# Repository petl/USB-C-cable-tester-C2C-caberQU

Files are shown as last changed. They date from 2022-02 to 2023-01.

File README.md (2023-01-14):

# USB C cable tester - C2C caberQU
Can my cable support USB 2.0/3.0/3.1/3.2, power delivery? Is a wire broken?

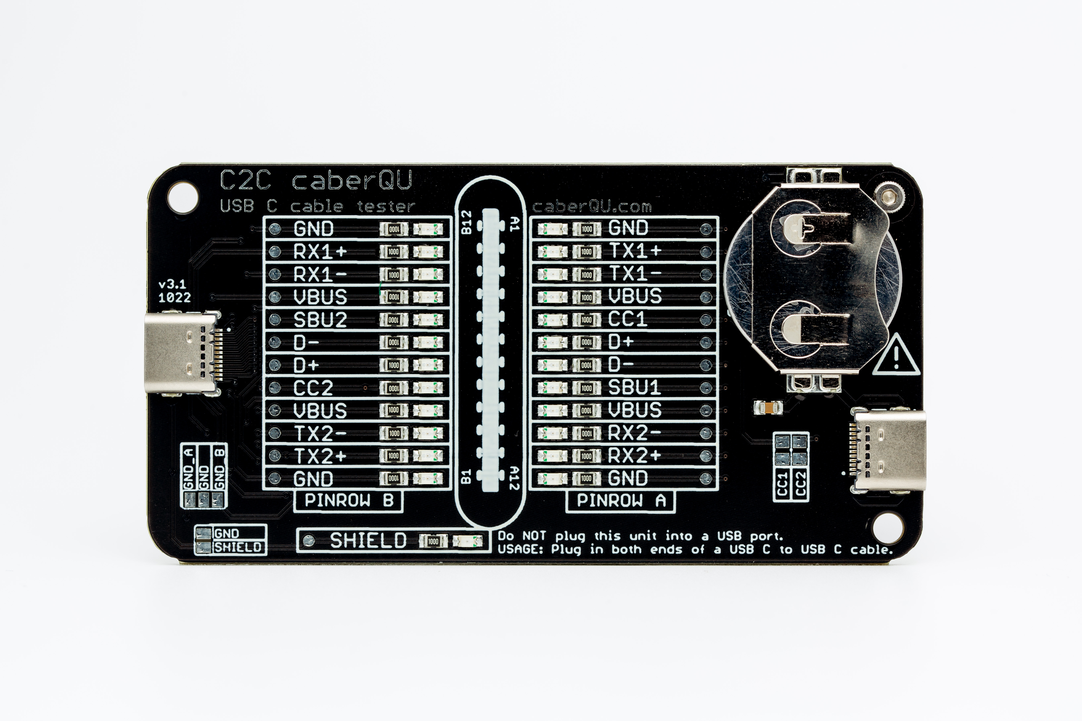
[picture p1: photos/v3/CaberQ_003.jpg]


Website: https://caberqu.com

#### What is it?

The C2C caberQU board applies a voltage to all pins of a cable and measures which ones are connected to the other end. It features LEDs for each of the 24 pins and even shield. So in total 25 LEDs offer all possible combinations for USB-C receptacle pin usage in different modes:

- USB 2.0/1.1
- USB Power Delivery
- USB 3.0/3.1/3.2
- Alternate Mode
- Debug Accessory Mode
- Audio Adapter Accessory Mode

See [the manual](https://github.com/petl/USB-C-cable-tester-C2C-caberQU/blob/main/documentation/v3/caberQU_manual_v3.2_compressed.pdf) to check which pin should be connected to where and get more infos about the USB-C connector. 

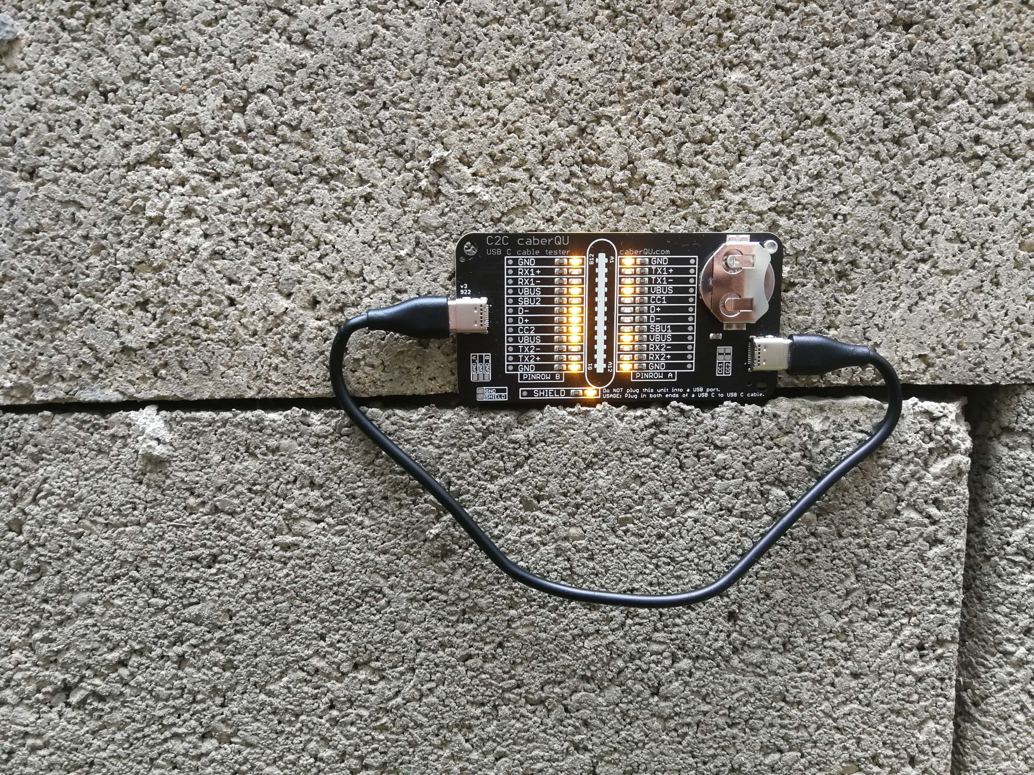
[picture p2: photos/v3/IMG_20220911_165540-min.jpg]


#### Why did you make it?

The amount of possible USB C cable combinations is endless. If you use the wrong cable, data transmission may be slower than possible or certain devices may not work at all. In the USB C standard, the cable plays an important role and has to advertise itself as such. All of them need to have certain pins connected, some need to be grounded, some need to have resistors attached. 

#### What makes it special?

Unfortunately there is no easy way to extract whether a certain cable can support a certain use case. If a cable has a broken pin, that makes it even worse, due to their unpredictable behavior. The C2C caberQU cable tester solves this once and for all. By flipping the USB connectors, the opposing LEDs for some pins light up due to them not being mirrored. That's on purpose and defined in the USB C standard. The product is sold with one CR2032, the PCB and some basic instructions. The USB C cable is not included. You have to extract the needed pins for your desired usage on your own, unfortunately that can not be done universally for all possible combinations.

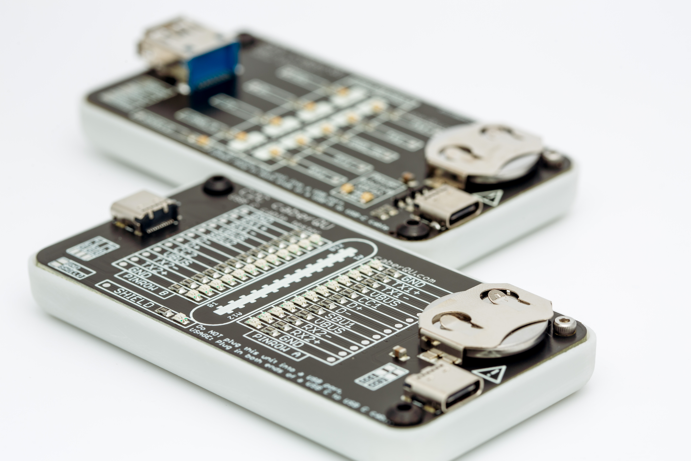
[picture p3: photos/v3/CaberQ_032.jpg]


No dedicated power supply is needed, all necessary power is supplied via the CR2032 battery.

Please note that if you have a cheaper shipping option I'm gladly using it and refunding you the difference. The item still is a prototype. It is working as intended, but funny quirks and other things are possible. It is not certified and only suited for prototyping. 

If you have any questions, just shoot me a message!

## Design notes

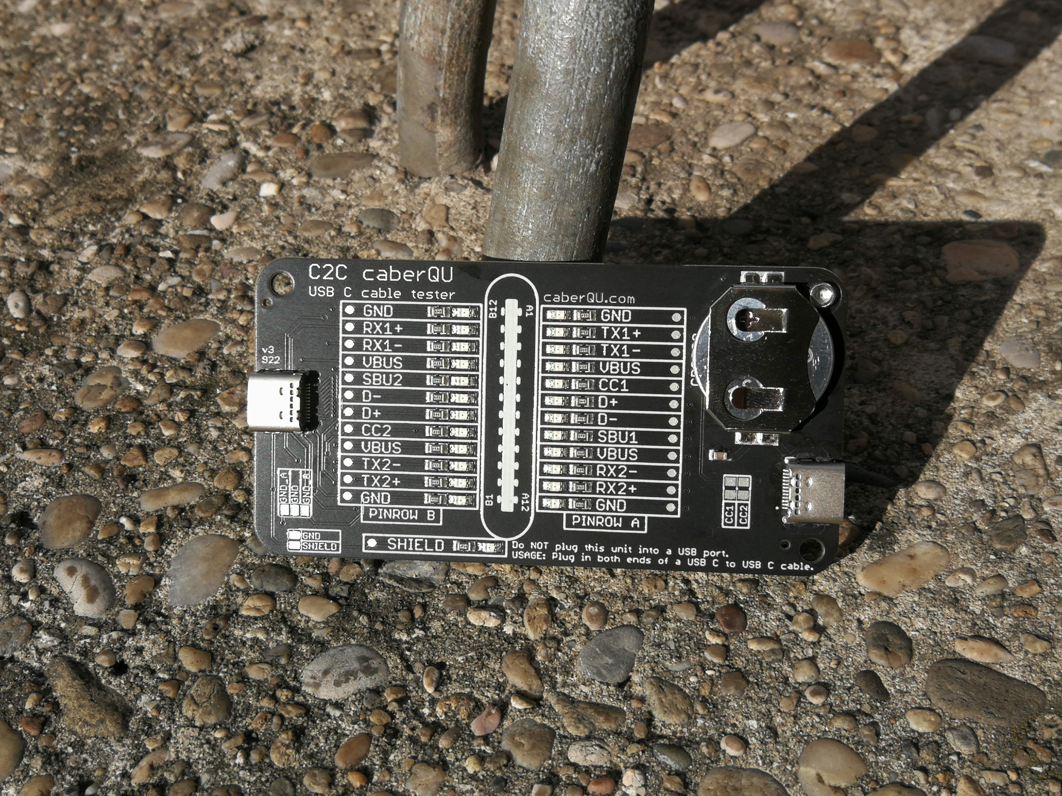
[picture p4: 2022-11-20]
photos/v3/IMG_20220911_164710-min.jpg

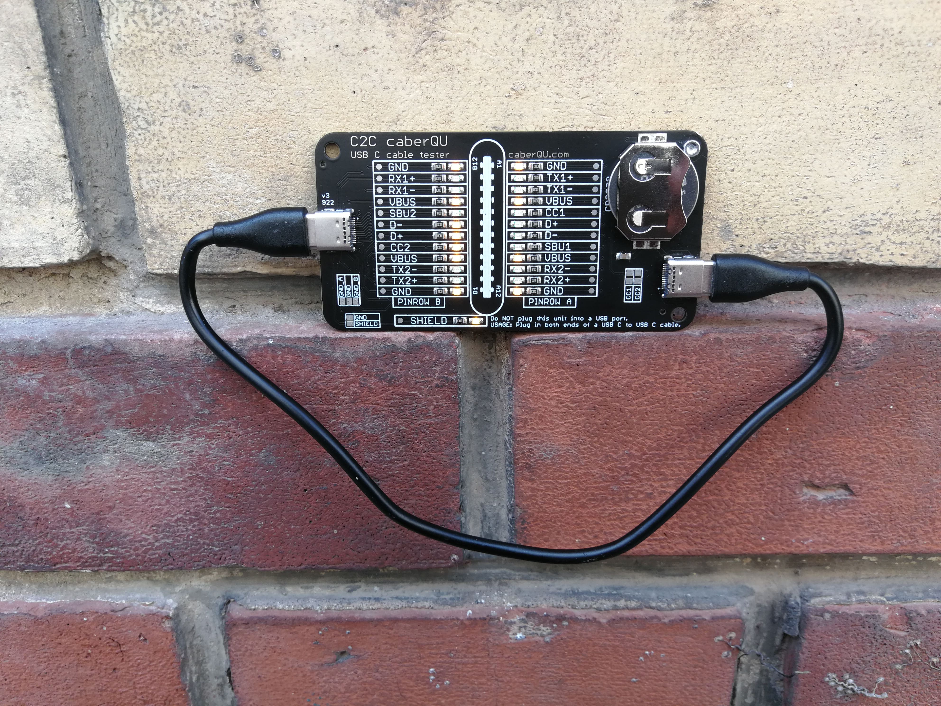
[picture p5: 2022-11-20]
photos/v3/IMG_20220911_165913-min.jpg

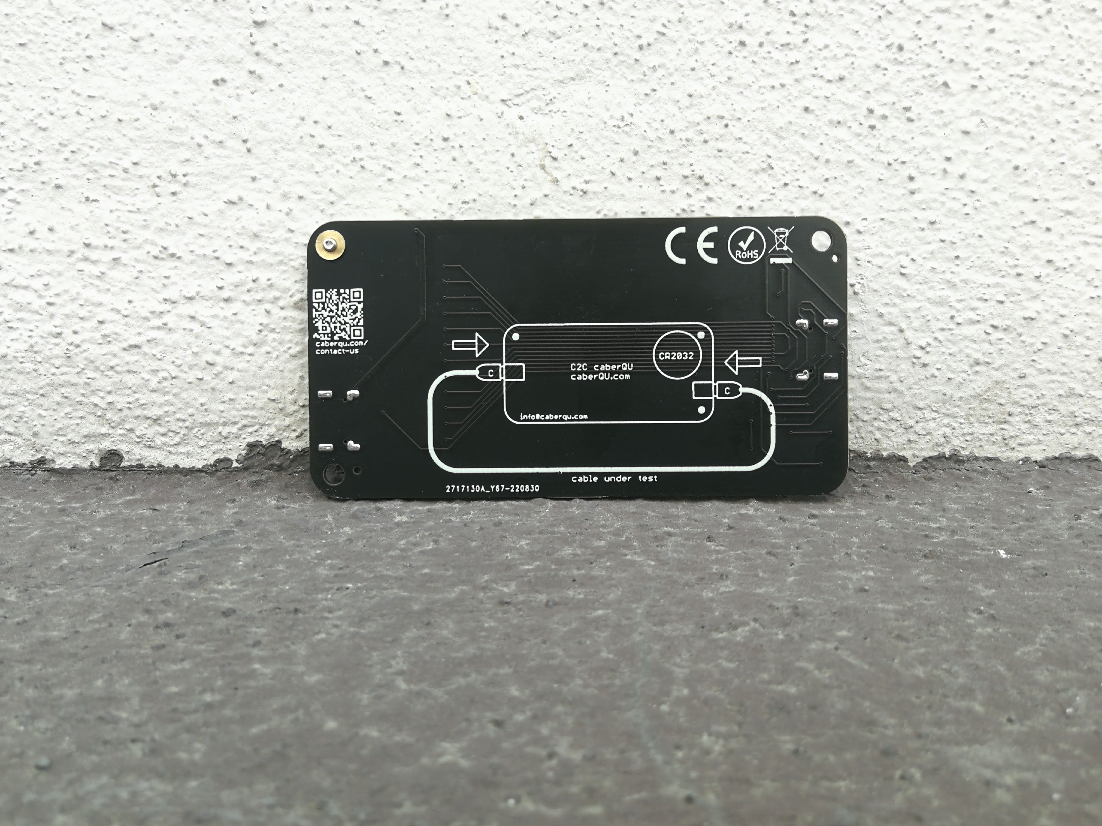
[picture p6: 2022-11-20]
photos/v3/IMG_20220911_163435-min.jpg

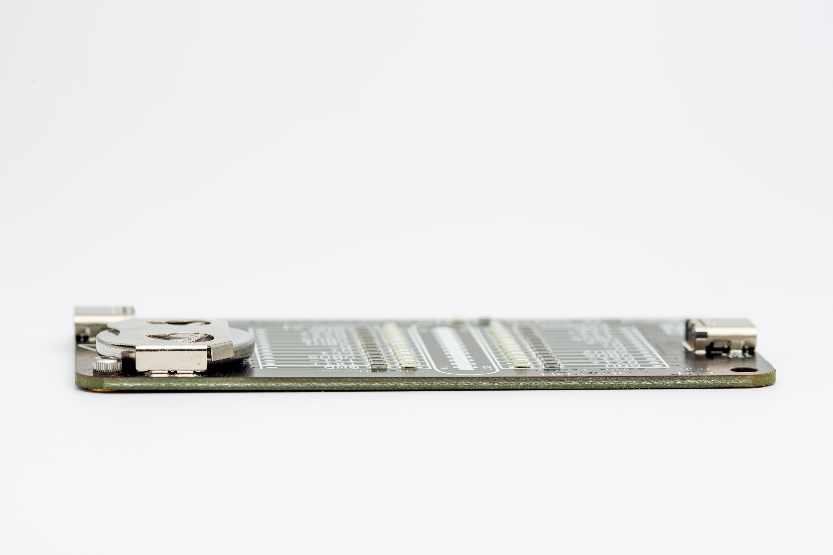
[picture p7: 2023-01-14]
photos/v3/CaberQ_010.jpg

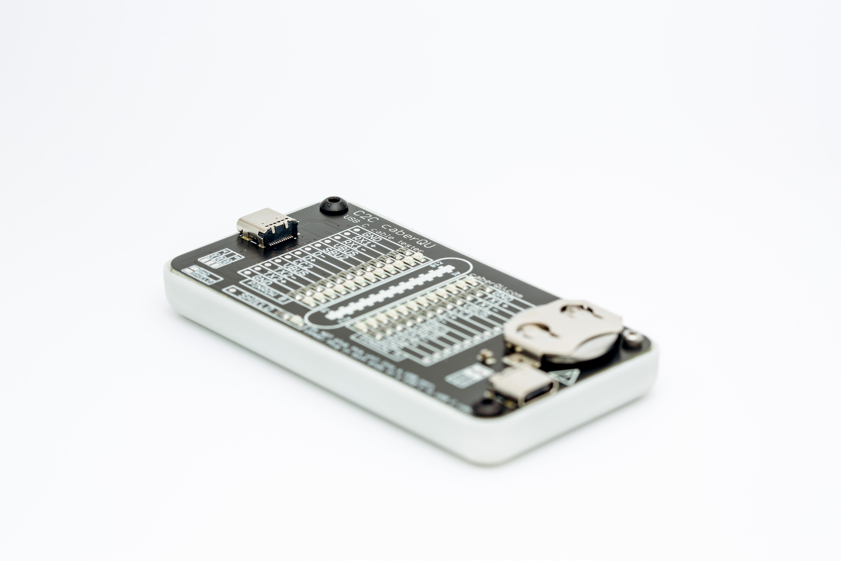
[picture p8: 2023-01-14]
photos/v3/CaberQ_027.jpg

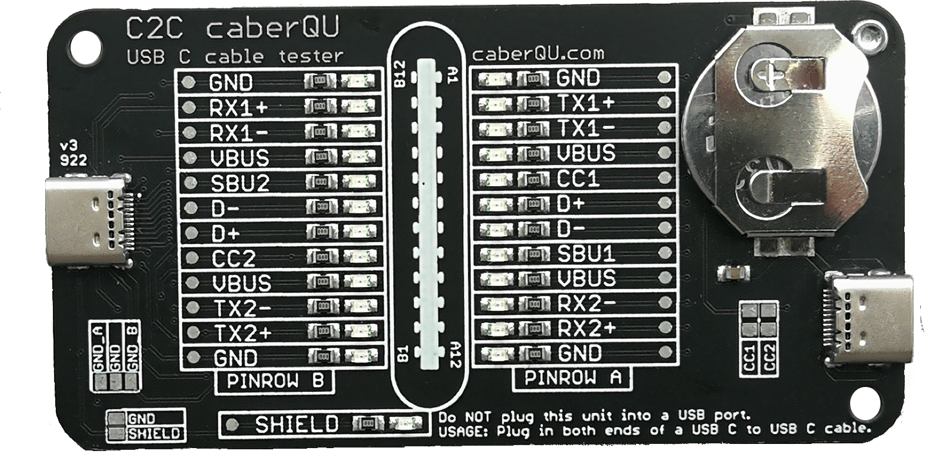
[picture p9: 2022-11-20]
photos/v3/C2C_front_transparent_bg.png

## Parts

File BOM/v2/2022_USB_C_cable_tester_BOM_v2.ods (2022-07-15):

Name | Value | Layout | Package
USB C cable tester
CR2032
PCB
CR2032 holder |  | G1 | CR2032-HOLDER-C964833
MLC Cap | 1u | C1 | C0805
LED yellow |  | LED1 LED2 LED3 LED4 LED5 LED6 LED7 LED8 LED9 LED10 LED11 LED12 LED13 LED14 LED15 LED16 LED17 LED18 LED19 LED20 LED21 LED22 LED23 LED24 LED25 | CHIPLED_0805
Resistor | 100 | R1 R2 R3 R4 R5 R6 R7 R8 R9 R10 R11 R12 R13 R14 R15 R16 R17 R18 R19 R20 R21 R22 R23 R24 R25 | R0805
USB C |  | J3 J4

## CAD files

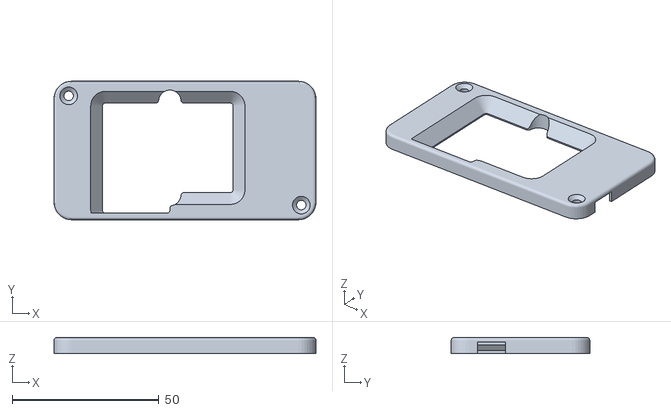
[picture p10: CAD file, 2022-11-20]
mechanics/stl/2022_USB_C_cable_tester_v3_full_enclosure_v4.STL
89.2 x 47.2 x 5.50

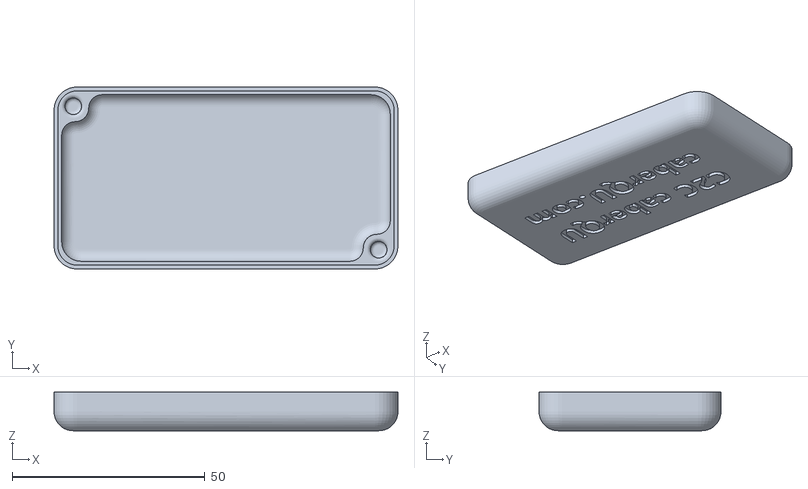
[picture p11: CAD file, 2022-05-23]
mechanics/stl/2022_USB_C_cable_tester_v2_Kickstarter_holder_M3_thinwall_v3.STL
89.2 x 47.2 x 10.0

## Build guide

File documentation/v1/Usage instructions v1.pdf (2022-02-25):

Usage instructions | 2.2022 p. 1/2

## Usage instructions

Congratulations on buying a great product for tinkering, debugging, testing and many other things. This manual will guide you through the usage instructions for the C2C caberQU USB C cable tester. Please read this carefully in order to be able to assemble everything without problems. If you face any problems, don‘t hesitate to write a mail.

Information:
Insert a CR2032 cell with the positive side („+“) facing up into the cell holder. Make sure not to short circuit it and don‘t use damaged or wrong batteries.
The C2C caberQU board applies a voltage to all pins of a cable and measures which ones are connected to the other end. It features LEDs for each of the 24 pins and even shield. So in total 25 LEDs offer all possible combinations for USB-C receptacle pin usage in different modes:
- USB 2.0/1.1
- USB Power Delivery
- USB 3.0/3.1/3.2
- Alternate Mode
- Debug Accessory Mode
- Audio Adapter Accessory Mode
See https://en.wikipedia.org/wiki/USB-C (https://en.wikipedia.org/wiki/USB-C#USB-C_receptacle_pin_usage_in_different_modes) to check which pin should be connected to where.
The amount of possible USB C cable combinations is endless. If you use the wrong cable, data transmission may be slower than possible or certain devices may not work at all. In the USB C standard, the cable plays an important role and has to advertise itself as such. All of them need to have certain pins connected, some need to be grounded, some need to have resistors attached. Unfortunately there is no easy way to extract whether a certain cable can support a certain use case. If a cable has a broken pin, that makes it even worse, due to their unpredictable behavior. The C2C caberQU cable tester solves this once and for all. By flipping the USB connectors, the opposing LEDs for some pins light up due to them not being mirrored. That's on purpose and defined in the USB C standard. The product is sold with one CR2032, the PCB and some basic instructions. You have to extract the needed pins for your desired usage on your own, unfortunately that can not be done universally for all possible combinations.
No dedicated power supply is needed, all necessary power is supplied via the CR2032 battery. Please note that if you have a cheaper shipping option I'm gladly using it and refunding you the difference. The item still is a prototype. It is working as intended, but funny quirks and other things are possible. It is not certified and only suited for prototyping.
If you have any questions, just shoot me a message!

Have fun tinkering and thanks for buying!

https://www.tindie.com/stores/petl/ | C2C caberQU - USB C cable tester v1

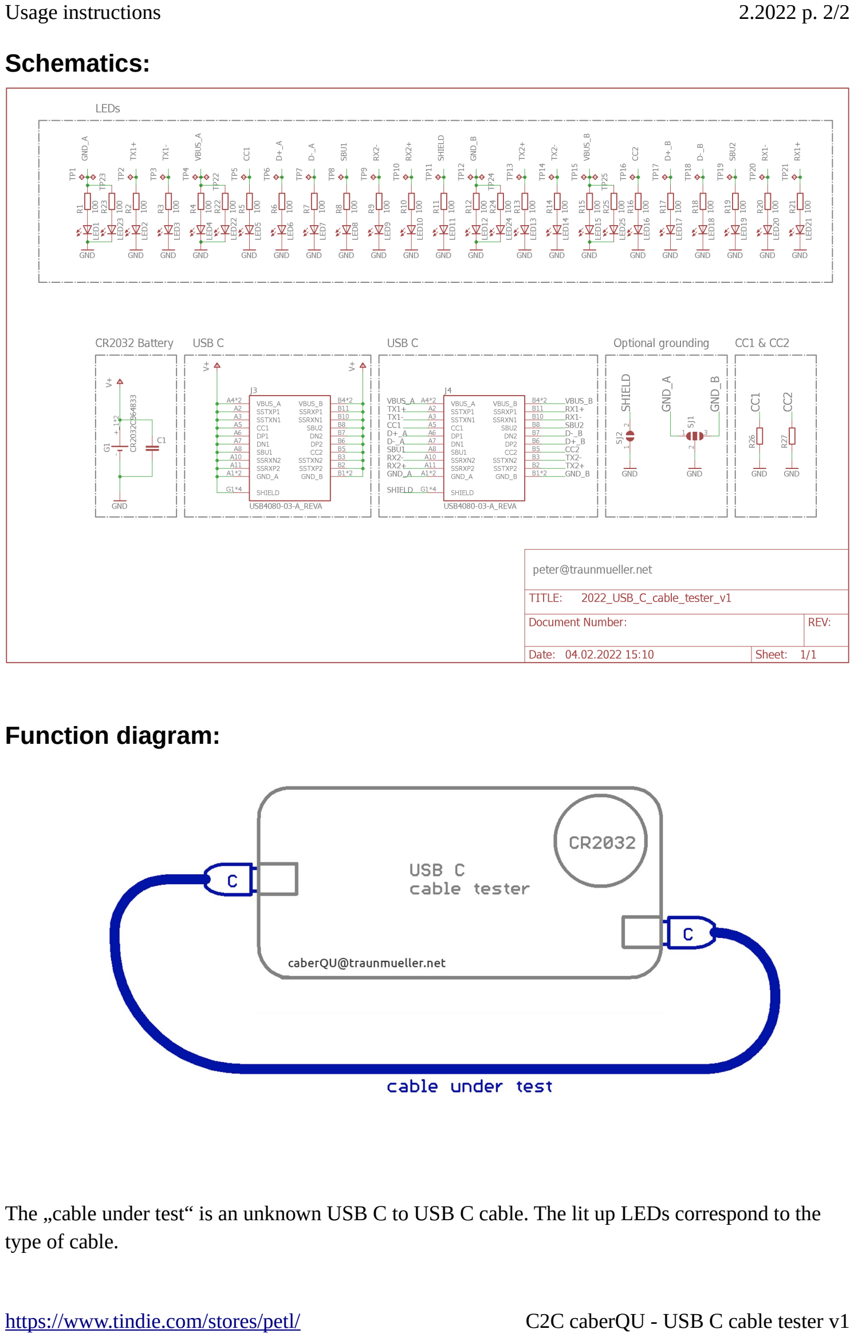
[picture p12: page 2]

Usage instructions | 2.2022 p. 2/2

Schematics:

Function diagram:

The „cable under test“ is an unknown USB C to USB C cable. The lit up LEDs correspond to the type of cable.

https://www.tindie.com/stores/petl/ | C2C caberQU - USB C cable tester v1

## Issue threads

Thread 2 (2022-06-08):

Feature Request: Add CPL for PCB Fab

CountParadox, 2022-06-08:
Hi friend,

Is it possible to add / generate a CPL file for sending to PCB Fab place like JLCPCB?

I want to have a batch of 30-50 of these made up, your Tindie store ran out of stock as I bought a few..
But I was hoping to avoid the SMT soldering myself..

Would it be possible to generate a file from the software you used to design it?

CountParadox, 2022-06-08:
JLC Has a number of articles showing how you could generate one in the software you used!

https://support.jlcpcb.com/category/78-smt-assembly

petl, 2022-06-12:
Hey,
I can send you a few boards, no problem, just write me a PM. I just want to avoid others selling this, as there is a Kickstarter campaign still on its way. If you have a bit more time, the tindie store will be stocked for sure.

CountParadox, 2022-06-12:
I'm not sure how to pm on GitHub...
I'm not looking to sell them, just get a bulk load for my co workers :) we go through a lot of USB C cables

CountParadox, 2022-08-10:
I did a jlcpcb order of 15 PCB as test; for anyone interested soldering by hand wasn't too hard. Took about 20 minutes for one board with an iron and smd rework station.

A form of the project has the BOM so you can order the correct parts from lscs. Was about $20 for the parts for $15 and $20 for the 15 PCBs.

For the remaining 14 I will use my local makerspace's smd oven to do 6-8 at once and smash the others out in an hour....

Still think it's weird for the designer to offer the Gerber's but not want people to make their own?

CountParadox, 2022-08-10:
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

OSHM34, 2022-08-10:
Good morning Lewys,

I'm, kind an of oldie 👴🏻,  electronics hobbyist.

I'm not sure if I understood correctly but if possible I would love to have
two of those boards.

If possible kindly advise how to proceed, have to pay etc.

Warm regards,
Hakan

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

petl, 2022-08-11:
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

Thanks for the feedback, the photos look great! I really like that all the necessary files are there and useful.
The p'n'p files are not there for the obvious reason that I would like to deter copycats from cloning the thing and selling it on e-bay/ali/.... I would like to enable people making a couple of units at home, that's why this repo exists, to give something back to the community.

I will continue to push newer updates and files to github in order for you to have the best possible experience with the C2C caberQU. Thanks for the forks, pull requests and propositions to make things better!

CountParadox, 2022-08-28:
I have since recreated the board in kicad and have generated  pnp files. contemplating if I should share them to my own repo..
I was able to order 20 boards fully assembled for around $30

Closed 2022-06-12.

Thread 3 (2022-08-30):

BOM Incomplete & Design files request

Schmarrele, 2022-08-30:
Hi,

I would like to order the board on my own, but the BOM seems to be incomplete.
Can you please update which specific MPN you use? (especially for the USB-C plugs and CR2032 holder)

Will you publish the (Eagle?) design files too?
Thanks

snadorp, 2022-09-13:
Very much interested in the Eagle files as well.

petl, 2023-09-11:
That's not really planned, the files are as a guide and not to make a commercial clone of this, sorry.

florisvde, 2025-08-12:
For anyone still looking for this: a good samaritan made a [fully open source version](https://github.com/CountParadox/USB-C-cable-tester-C2C-open) of this project, with a [fully specified BOM](https://github.com/CountParadox/USB-C-cable-tester-C2C-open/blob/main/BOM/Kickstarter%20Edition/2022_USB_C_cable_tester_BOM_LCSC_v1.csv). Not sure if that BOM is compatible with the v2 gerbers posted here by @petl, so I'd suggest having @CountParadox's boards made instead.

In @petl's [manual](https://github.com/petl/USB-C-cable-tester-C2C-caberQU/blob/main/documentation/v2/caberQU_manual_v2.3.pdf) the most important MPNs can also be found:

| Reference Designator | QTY | MPN |
| -------- | ------- | ------- |
| J3-4  | 2 | [GCT USB4080-03-A](https://www.digikey.nl/en/products/detail/gct/USB4080-03-A/14659819) |
| G1 | 1 | [MYOUNG MY-2032-12](https://www.lcsc.com/product-detail/C964833.html) |

Since I'm ordering parts from DigiKey, I'm going to try the following parts for @petl's v2 PCB:
| Reference Designator | QTY | MPN |
| -------- | ------- |------- |
| J3-J4  | 2 | [GCT USB4080-03-A](https://www.digikey.nl/en/products/detail/gct/USB4080-03-A/14659819) |
| G1 | 1 | [Keystone 3034](https://www.digikey.nl/en/products/detail/keystone-electronics/3034/4499289) |
| LED1-LED25 | 25 | [Lite-On Inc. LTST-C171KSKT](https://www.digikey.nl/en/products/detail/liteon/LTST-C171KSKT/386803) |
| R1-R25 | 25 | [YAGEO RT0805DRE07100RL](https://www.digikey.nl/en/products/detail/yageo/RT0805DRE07100RL/1078369) |
| C1 | 1 | [YAGEO CC0805KKX7R7BB105](https://www.digikey.nl/en/products/detail/yageo/CC0805KKX7R7BB105/2103103) |

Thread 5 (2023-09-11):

Clarify documentation to reflect USB 3.2 Gens please ...

gjashley, 2023-09-11:
... i.e. 3.2 Gen 1, 3.2Gen 2x1, 3.2 Gen 2x2 (also 4 and Thunderbolt if that can be derived from the cable)
I'm so confused :/

petl, 2023-09-11:
USB generations are not really clear and have unfortunately been changed by the USB foundation quite often. The unit can differentiate if the pins are available, but not if a certain speed can or is actually used by the connected devices.

Closed 2023-09-11.

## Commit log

2022-02-25 Gerber files for production v1
2022-02-25 Bill of Materials v1
    [2022_USB_C_cable_tester_BOM_v1.ods]
2022-02-25 v1 schematics and instructions
2022-04-14 Add BOM for LCSC
    [2022_USB_C_cable_tester_BOM_LCSC_v1.csv]
2022-05-23 case v3 for PCB v2
    [2022_USB_C_cable_tester_v2_Kickstarter_holder_M3_thinwall_v3.STL]
2022-05-23 PCB v2 drawing
2022-05-23 case v3 photos
2022-07-15 gerbers for v2
2022-07-15 BOM for v2
    [2022_USB_C_cable_tester_BOM_LCSC_v1.csv, 2022_USB_C_cable_tester_BOM_v1.ods, 2022_USB_C_cable_tester_BOM_v2.ods]
2022-11-20 case full enlosure v4
    [2022_USB_C_cable_tester_v3_full_enclosure_v4.STL]
2022-11-20 case fulmanual and photos v3
